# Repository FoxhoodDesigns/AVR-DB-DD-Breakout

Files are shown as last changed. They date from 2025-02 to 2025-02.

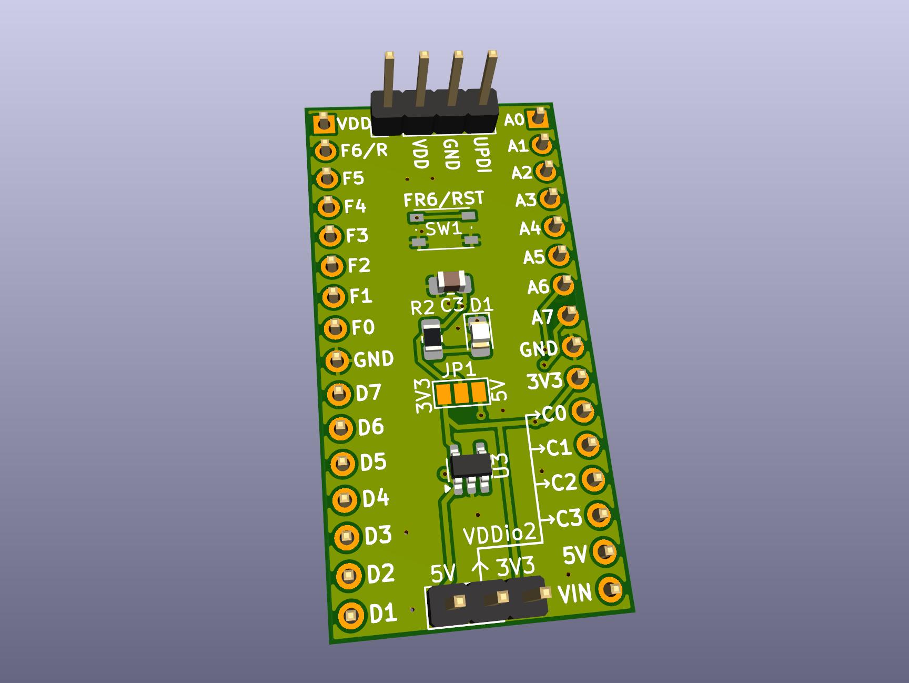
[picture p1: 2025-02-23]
AVR128 Breakout.jpg

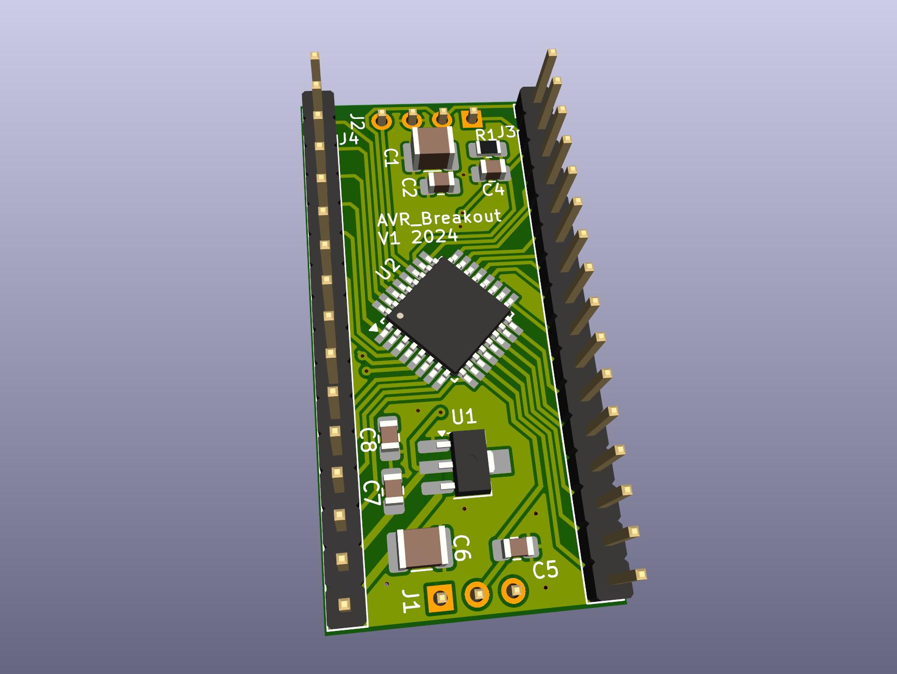
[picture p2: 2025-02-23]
AVR128 Breakout back.jpg

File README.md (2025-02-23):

# AVR DB/DD Breakout

This little Board is designed to allow for easy experimentation with AVR128DB32 and AVR64DD32 Microcontrollers.
It is very minimalist with only the AVR itself, A pair of standard LDO linear regulators (1117-5V and a 2112-3.3V), A simple power indicator and some jumpers for configuring the board and/or VDDIO2 to 3.3V or 5V.
Note: This relies on the Internal Oscillator which on the new generation of AVR chips can achieve pretty high speeds.

Both the DB and DD work. The DD is more suitable as a general purpose and is fairly cheap (comparable to a ATMega32PB), while the DB is more for bigger stuff. As one might guess by having up to a whopping 128Kb of Flash for code.

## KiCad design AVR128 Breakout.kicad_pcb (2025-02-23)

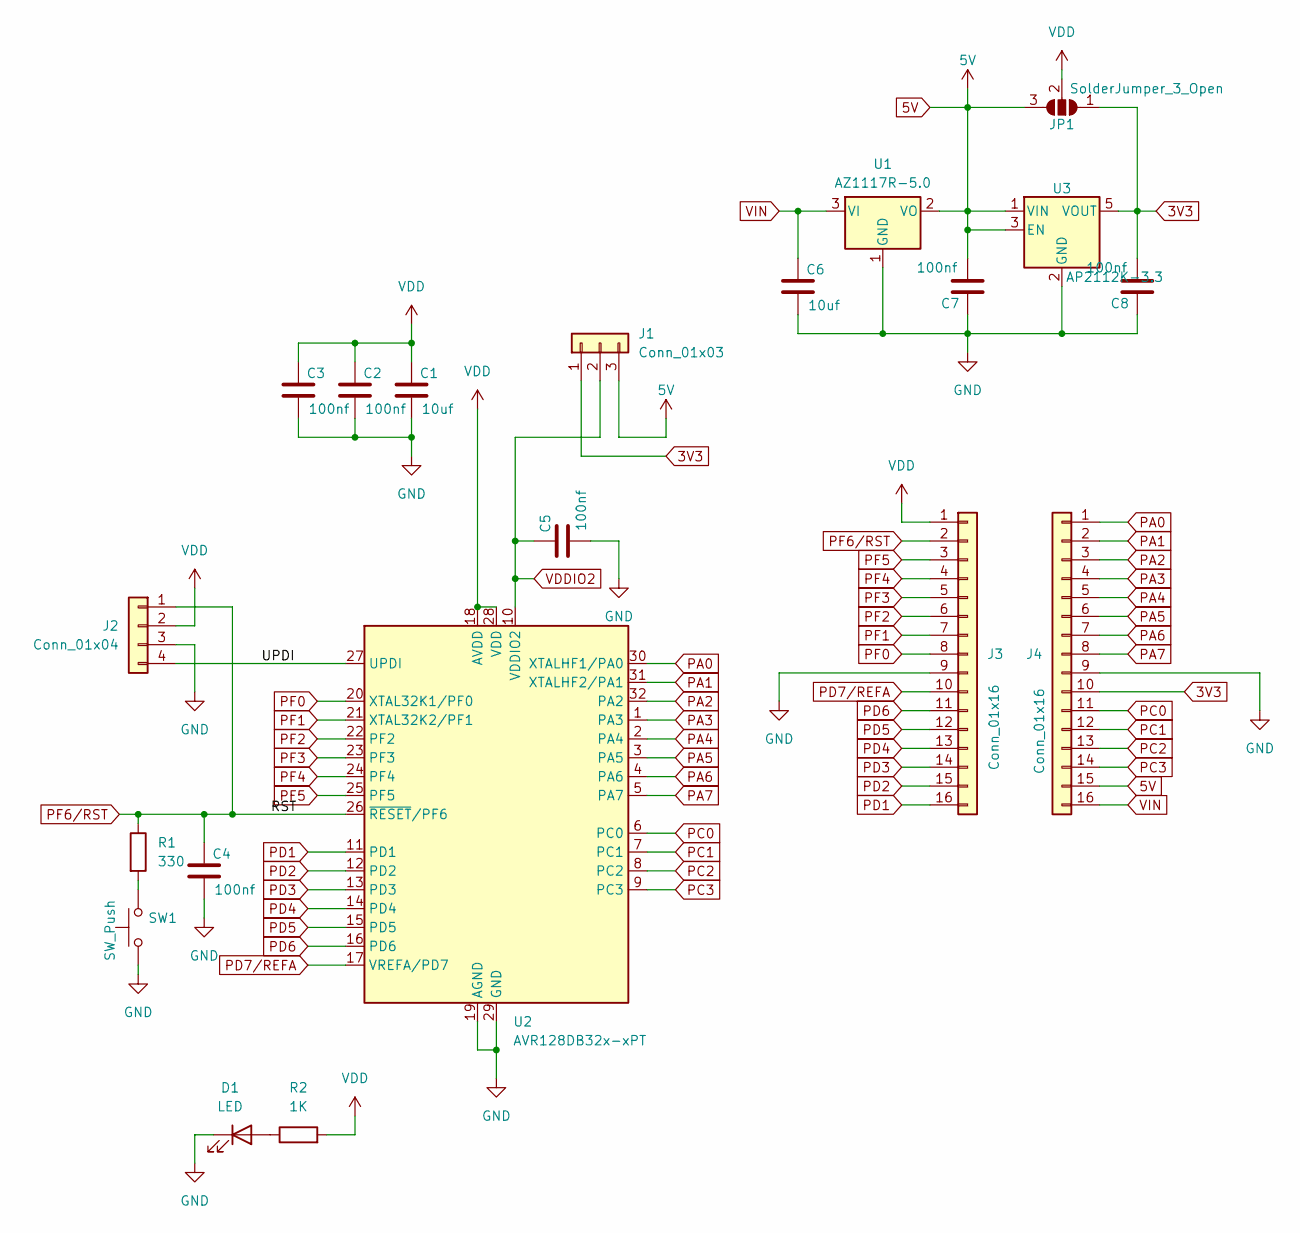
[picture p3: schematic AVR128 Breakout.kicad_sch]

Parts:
C1, C6: 10uf; C_1210_3225Metric_Pad1.33x2.70mm_HandSolder
C2, C3, C4, C5, C7, C8: 100nf; C_0805_2012Metric_Pad1.18x1.45mm_HandSolder
D1: LED; LED_0805_2012Metric_Pad1.15x1.40mm_HandSolder
J1: Conn_01x03; PinHeader_1x03_P2.54mm_Vertical
J2: Conn_01x04; PinHeader_1x04_P2.54mm_Vertical
J3, J4: Conn_01x16; PinHeader_1x16_P2.54mm_Vertical
JP1: SolderJumper_3_Open; SolderJumper-3_P1.3mm_Open_Pad1.0x1.5mm_NumberLabels
R1: 330; R_0805_2012Metric_Pad1.20x1.40mm_HandSolder
R2: 1K; R_0805_2012Metric_Pad1.20x1.40mm_HandSolder
SW1: SW_Push; SW_Push_1P1T_NO_Vertical_Wuerth_434133025816
U1: AZ1117R-5.0; SOT-89-3_Handsoldering
U2: AVR128DB32x-xPT; TQFP-32_7x7mm_P0.8mm
U3: AP2112K-3.3; SOT-23-5

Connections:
3V3: C8.2, J1.1, J4.10, JP1.1 (A), U3.5 (VOUT)
5V: C7.2, J1.3, J4.15, JP1.3 (B), U1.2 (VO), U3.1 (VIN), U3.3 (EN)
/UPDI: J2.4, U2.27 (UPDI)
GND: C1.2, C2.2, C3.2, C4.2, C5.2, C6.2, C7.1, C8.1, D1.1 (K), J2.3, J3.9, J4.9, SW1.1, U1.1 (GND), U2.19 (AGND), U2.29 (GND), U3.2 (GND)
unnamed: D1.2 (A), R2.1
unnamed: R1.2, SW1.2
PA0: J4.1, U2.30 (XTALHF1/PA0)
PA1: J4.2, U2.31 (XTALHF2/PA1)
PA2: J4.3, U2.32 (PA2)
PA3: J4.4, U2.1 (PA3)
PA4: J4.5, U2.2 (PA4)
PA5: J4.6, U2.3 (PA5)
PA6: J4.7, U2.4 (PA6)
PA7: J4.8, U2.5 (PA7)
PC0: J4.11, U2.6 (PC0)
PC1: J4.12, U2.7 (PC1)
PC2: J4.13, U2.8 (PC2)
PC3: J4.14, U2.9 (PC3)
PD1: J3.16, U2.11 (PD1)
PD2: J3.15, U2.12 (PD2)
PD3: J3.14, U2.13 (PD3)
PD4: J3.13, U2.14 (PD4)
PD5: J3.12, U2.15 (PD5)
PD6: J3.11, U2.16 (PD6)
PD7/REFA: J3.10, U2.17 (VREFA/PD7)
PF0: J3.8, U2.20 (XTAL32K1/PF0)
PF1: J3.7, U2.21 (XTAL32K2/PF1)
PF2: J3.6, U2.22 (PF2)
PF3: J3.5, U2.23 (PF3)
PF4: J3.4, U2.24 (PF4)
PF5: J3.3, U2.25 (PF5)
PF6/RST: C4.1, J2.1, J3.2, R1.1, U2.26 (~RESET/PF6)
VDD: C1.1, C2.1, C3.1, J2.2, J3.1, JP1.2 (C), R2.2, U2.18 (AVDD), U2.28 (VDD)
VDDIO2: C5.1, J1.2, U2.10 (VDDIO2)
VIN: C6.1, J4.16, U1.3 (VI)

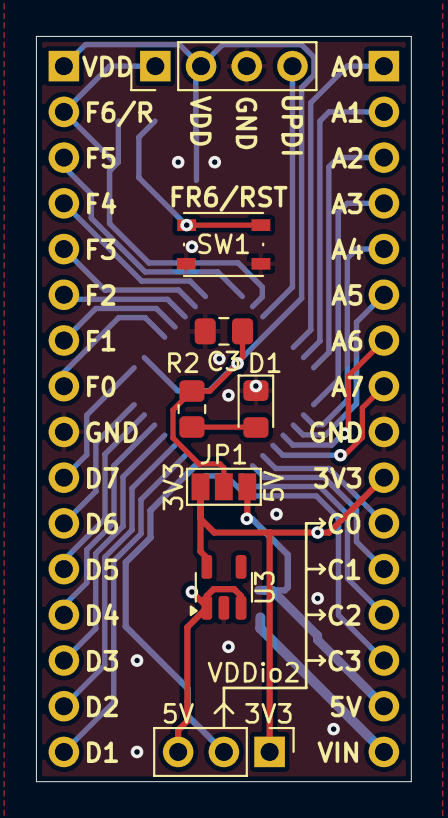
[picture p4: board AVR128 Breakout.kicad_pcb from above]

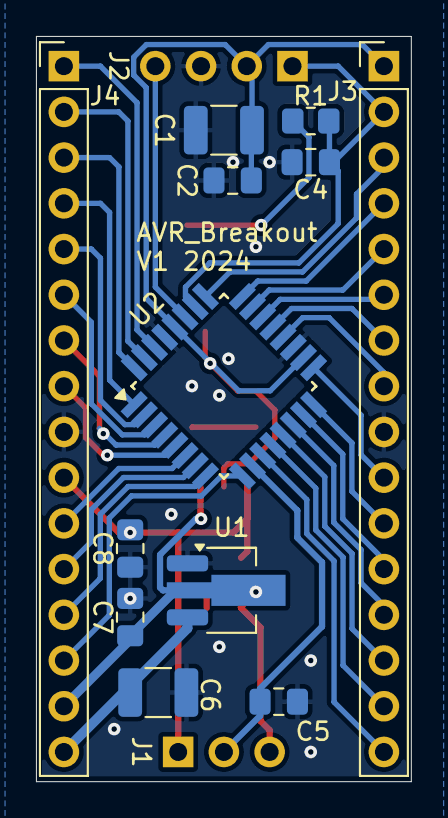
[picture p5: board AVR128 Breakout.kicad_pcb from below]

Board: 2 copper layers, 20.8 x 41.4 mm, 20 parts (12 on the bottom side), 35 nets.

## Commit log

2024-08-14 Add files via upload
    Add 3D render of board
2025-02-23 Initial Upload
    [AVR128 Breakout-B_Cu.gbr, AVR128 Breakout-B_Mask.gbr, AVR128 Breakout-B_Paste.gbr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]
